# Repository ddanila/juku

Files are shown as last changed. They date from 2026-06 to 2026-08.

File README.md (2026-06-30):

# Juku models

OpenSCAD models for restoring and reproducing parts of the Juku computer.
Technical dimensions and modeling details are in [NOTES.md](NOTES.md).

> [!NOTE]
> This project is an experiment in creating medium-complexity 3D models
> with an LLM. The OpenSCAD code was written through Codex with almost no
> manual code edits.

## Models

### Keycap

The keycap has a dished top, rounded chamfered sides, a central spring rod,
contact pushers, and side latches that clip into the switch housing.

|  | Top | Bottom |
| --- | --- | --- |
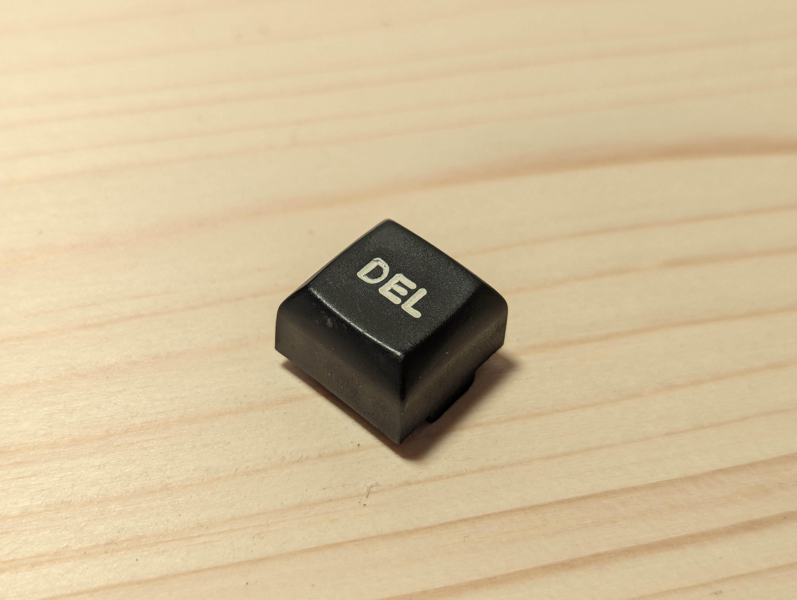
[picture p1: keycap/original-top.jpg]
Top of an original Juku keycap
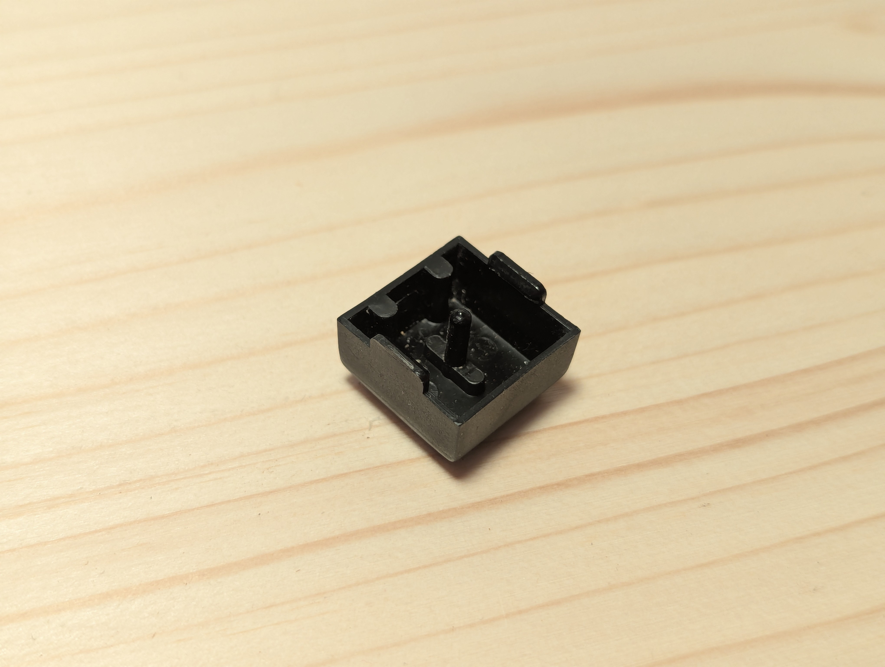
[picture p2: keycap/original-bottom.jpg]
Bottom of an original Juku keycap
| Original |  |  |
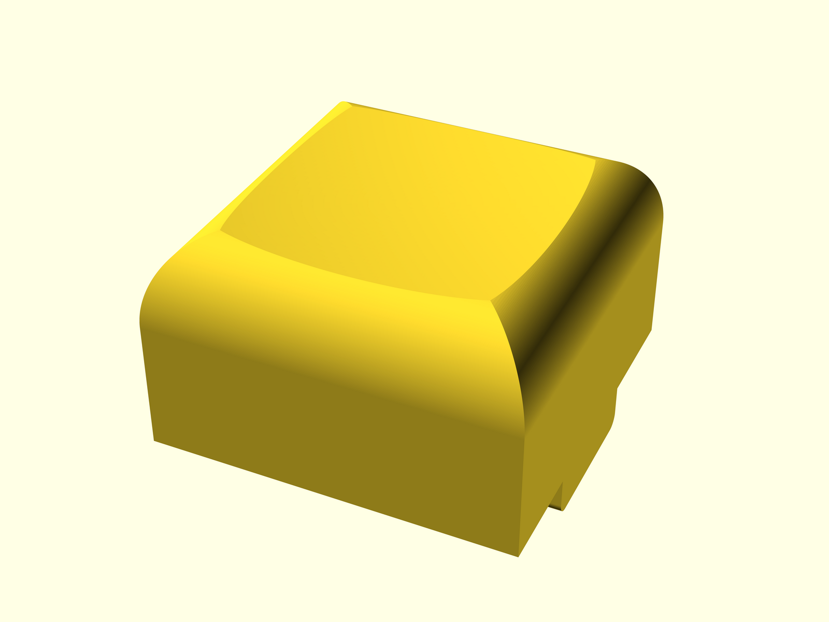
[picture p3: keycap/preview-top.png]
Top keycap render
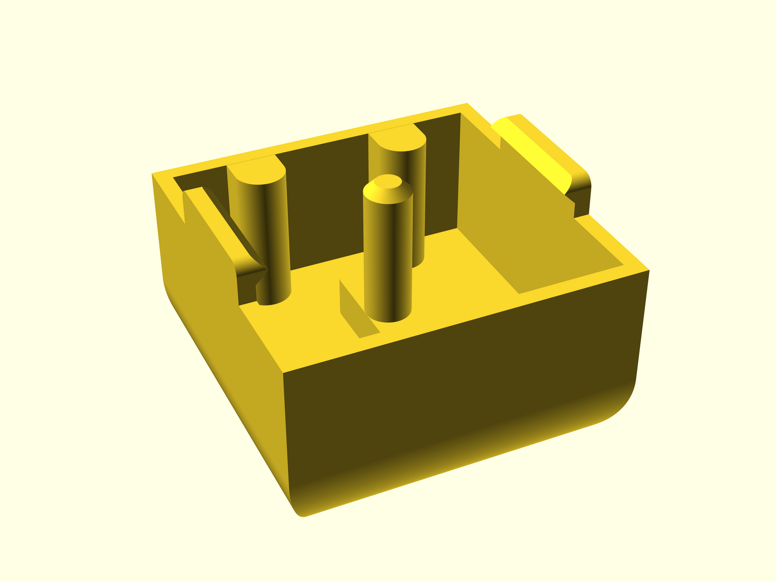
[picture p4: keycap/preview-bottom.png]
Bottom keycap render
| Render |  |  |
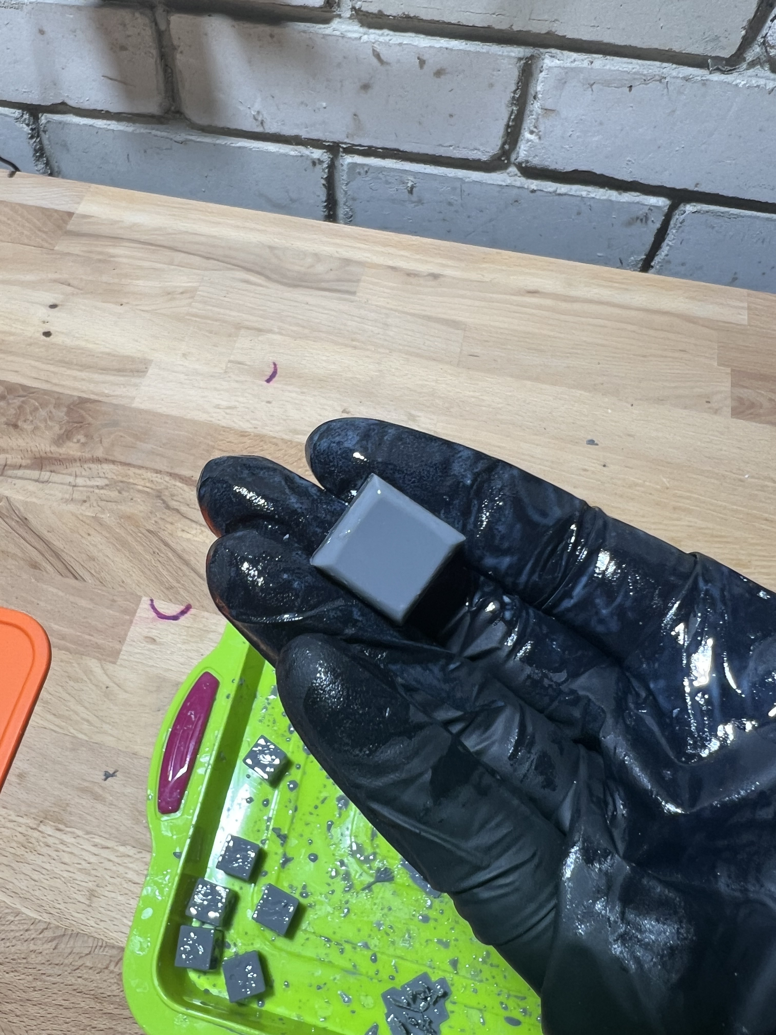
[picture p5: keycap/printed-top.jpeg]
Top of the printed keycap
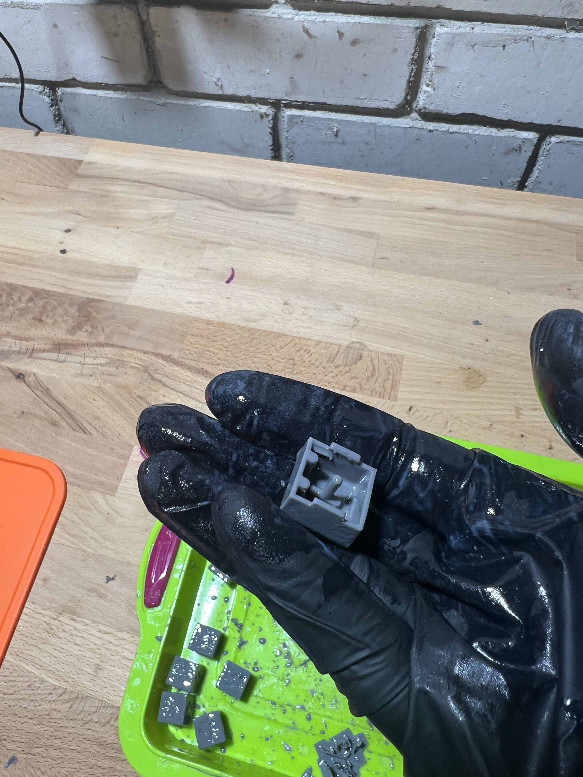
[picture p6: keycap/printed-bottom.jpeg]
Bottom of the printed keycap
| Print |  |  |

- Source: [`keycap/juku-keycap.scad`](keycap/juku-keycap.scad)
- Printable model: [`keycap/juku-keycap.stl`](keycap/juku-keycap.stl)

### Bottom Case

The bottom part of the computer case includes the PCB opening and guide,
leg mounting holes, and reinforced PCB support mounts.

| Interior | Underside (logo) | Rear edge (supports) |
| --- | --- | --- |
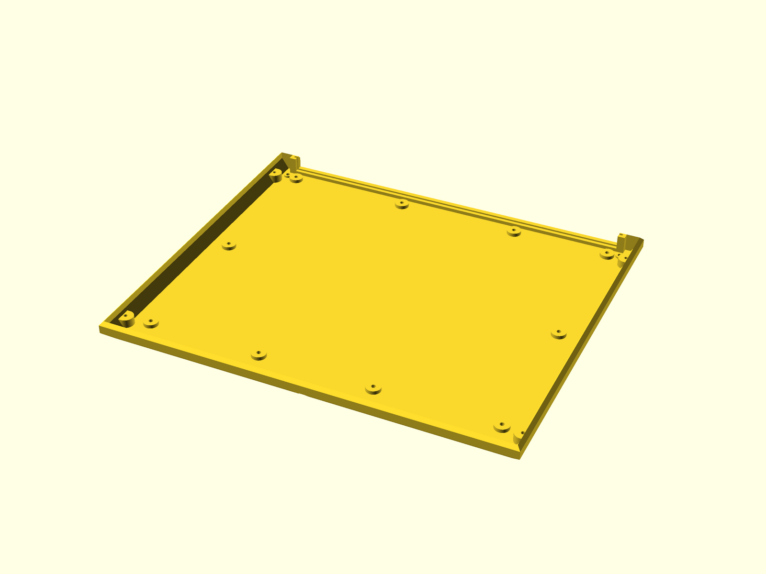
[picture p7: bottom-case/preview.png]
Bottom case interior render
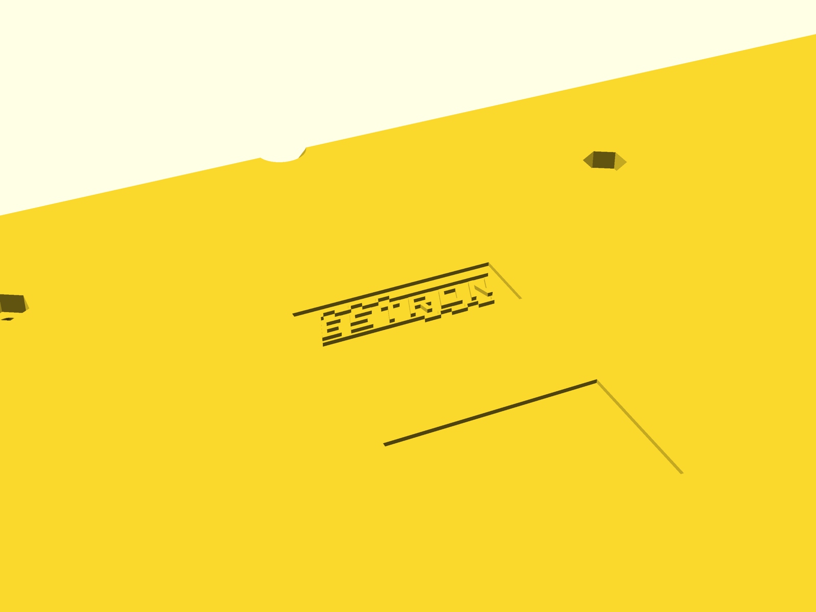
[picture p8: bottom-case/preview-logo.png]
Bottom case underside render with logo
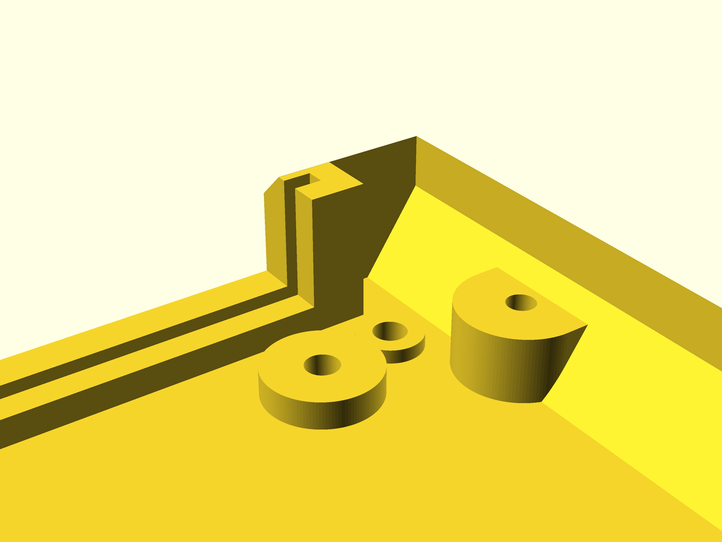
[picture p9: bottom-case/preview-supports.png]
Bottom case rear-edge render showing guide rails and support bosses
|  |  |  |

- Source: [`bottom-case/juku-bottom-case.scad`](bottom-case/juku-bottom-case.scad)
- Printable model: [`bottom-case/juku-bottom-case.stl`](bottom-case/juku-bottom-case.stl)

### Top Case

The top case is an open-bottom shell with a sloped keyboard face, keyboard
opening, side-wall chamfers, rear ventilation slots, a recessed logo area,
LED opening, and switch access opening.

| Exterior | Interior |
| --- | --- |
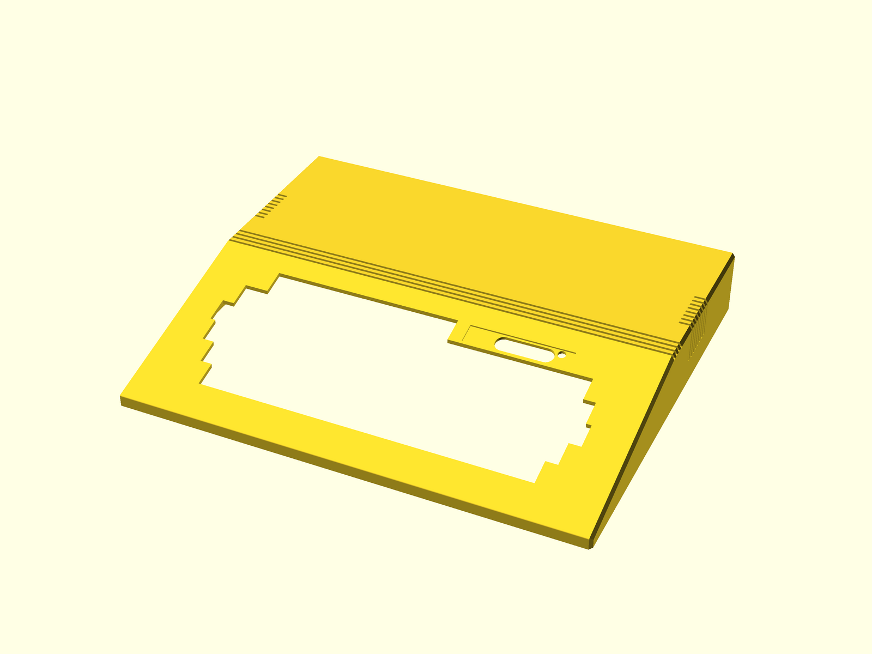
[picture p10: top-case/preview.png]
Top case exterior render
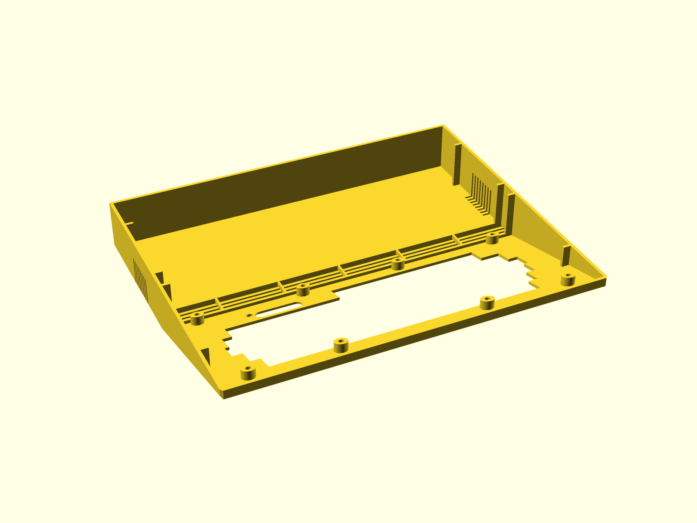
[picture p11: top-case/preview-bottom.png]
Top case interior render
|  |  |

- Source: [`top-case/juku-top-case.scad`](top-case/juku-top-case.scad)
- Printable model: [`top-case/juku-top-case.stl`](top-case/juku-top-case.stl)

### Legs

The rubber legs are simple stepped push-in feet matched to the bottom-case
mounting holes.

| Render |
| --- |
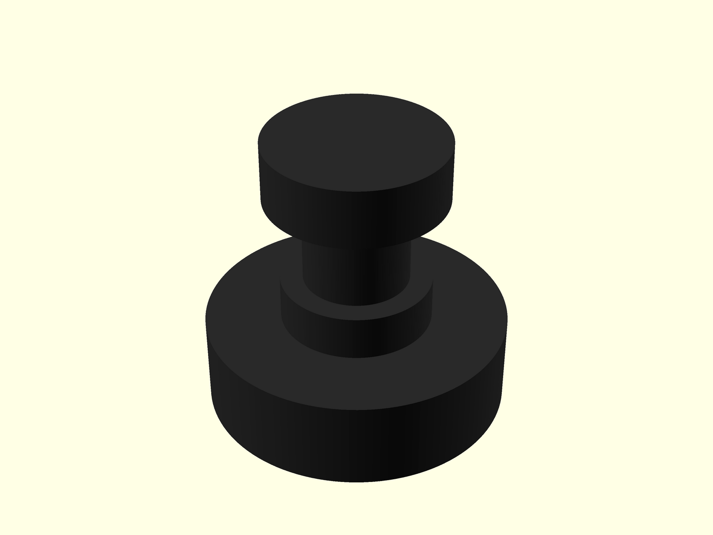
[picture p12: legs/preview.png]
Leg render
|  |

- Source: [`legs/juku-leg.scad`](legs/juku-leg.scad)
- Printable/reference model: [`legs/juku-leg.stl`](legs/juku-leg.stl)
- Assembly check: [`assembly/juku-bottom-with-legs.scad`](assembly/juku-bottom-with-legs.scad)

## Commands

```bash
# Open a model for interactive inspection.
./scripts/open-keycap.sh
./scripts/open-bottom-case.sh

# Validate both models without changing committed artifacts.
./scripts/check-render.sh

# Regenerate committed STL files and previews.
./scripts/export-stls.sh
./scripts/render-previews.sh

# Export the bottom-case XY projection for LibreCAD.
openscad-nightly \
    -o bottom-case/projection-xy.dxf \
    bottom-case/projection-xy.scad
```

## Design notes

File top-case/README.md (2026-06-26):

# Juku Top Case

OpenSCAD model for the top half of the Juku computer case.

Top case preview

## Files

- Source: [`juku-top-case.scad`](juku-top-case.scad)
- Printable/reference model: [`juku-top-case.stl`](juku-top-case.stl)
- Preview render: [`preview.png`](preview.png)

## Current Model

The top case is an open-bottom shell with a sloped keyboard face, keyboard
opening, side-wall chamfers, rear ventilation slots, a recessed logo area, LED
hole, and rounded config-switch access opening.

The main dimensions and feature offsets are named near the top of
`juku-top-case.scad`. Keep changes parameterized there where practical.

## Regeneration

From the repository root:

```bash
./scripts/export-stls.sh
./scripts/render-previews.sh
```

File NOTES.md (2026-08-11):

# Juku Modeling Notes

## OpenSCAD command

OpenSCAD is installed through Snap as `openscad-nightly`, not `openscad`.

```bash
openscad-nightly --version
```

If a plain `openscad` command is useful, add this alias to `~/.bashrc`:

```bash
alias openscad=openscad-nightly
```

On macOS the binary is inside the app bundle: `/Applications/OpenSCAD.app/Contents/MacOS/OpenSCAD`.

## Repository layout

Each modeled component keeps its source and generated artifacts together:

| Component | Source | Generated artifacts |
| --- | --- | --- |
| Keycap | `keycap/juku-keycap.scad` | `keycap/juku-keycap.stl`, `keycap/preview-*.png` |
| Bottom case | `bottom-case/juku-bottom-case.scad` | `bottom-case/juku-bottom-case.stl`, `bottom-case/preview.png` |
| Legs | `legs/juku-leg.scad` | `legs/juku-leg.stl` |

Regenerate STL files with `./scripts/export-stls.sh` and previews with
`./scripts/render-previews.sh`. Generated model artifacts should not be
edited by hand.

The preview script renders above the target resolution and downscales to
1600x1200 because OpenSCAD's CLI renders without antialiasing. It uses
OpenSCAD's built-in `Monotone` color scheme so subtraction-cut surfaces do
not get a distinct back-face color.

`keycap/original-*.jpg` are reference photos of an original keycap.
`keycap/printed-*.jpeg` are photos of a real resin print, with metadata
stripped.

## Iteration workflow

After each modeling change:

1. Render the SCAD file to an STL to catch syntax and geometry errors.

   ```bash
   ./scripts/check-render.sh
   ```

2. Confirm OpenSCAD reports a manifold 3D object with `Status: NoError`.

3. Open the SCAD file in OpenSCAD for manual review from a normal desktop terminal or the application launcher.

   ```bash
   ./scripts/open-keycap.sh
   ./scripts/open-bottom-case.sh
   ```

Codex can run the automated render check reliably. It can also attempt to launch the OpenSCAD UI, but Snap/desktop session handling may make that window flash briefly or disappear, so manual review is best started from the user's desktop session.

## Modeling notes

Large spheres used for shallow cuts need a high local segment count. A large-radius sphere with the global `$fn = 48` can technically intersect the model but look flat in OpenSCAD because the visible patch is a low-resolution facet. Use a local `$fn`, for example:

```scad
sphere(r = top_dish_radius, $fn = top_dish_segments);
```

## Bottom case dimensions

All dimensions are in millimeters.

| Dimension | Value |
| --- | ---: |
| Outer width (X) | 340 |
| Outer depth (Y) | 290 |
| Outer height (Z) | 18 |
| Case thickness | 3 |
| Front and side bottom chamfer | 8 at 45 degrees |
| Top rim chamfer | 3 at 45 degrees, downward toward outside |
| Rear PCB opening | 300 wide x 12 high, centered horizontally and open at top |
| Rear outer guide rail | 312 long x 4 deep x 15 high |
| Rear guide channel | 2 deep, with the case floor at its bottom |
| Rear inner guide rail | 306 long x 3 deep x 15 high |
| Leg hole centers | 15 from each adjacent outer edge |
| Leg through-hole | 3.5 diameter |
| Leg exterior counterbore | 5 diameter x 1.5 deep |
| Leg interior reinforcement | 7 diameter x 1.5 high |
| Leg through-hole depth | 4.5 including floor and reinforcement boss |
| Leg hole cylinder segments | 128 |
| PCB support through-hole | 3.5 diameter |
| PCB support exterior nut pocket | Hexagonal, 6 across flats x 3 deep |
| PCB support interior reinforcement | 12 diameter x 3 high |
| PCB support rear row centers | X: 25, 129, 233, 315; Y: 272 |
| PCB support side centers | X: 25, 315; Y: 152 |
| PCB support front row centers | X: 25, 120, 215, 315; Y: 32 |
| Lid mount side centers | X: 7, 333; Y: 25, 265 |
| Lid mount front center | X: 170; Y: 7 |
| Lid mount through-hole | 3 diameter |
| Lid mount exterior recess | 8 wide x 6.5 deep, round-ended and projected to outer edge |
| Lid mount interior reinforcement | 13 diameter x 7 high, clipped to D shape |
| Logo plaque | 30 wide x 10 deep x 0.6 recessed into underside |
| Logo plaque front offset | 50 to front edge |
| Logo relief | 0.6 above recessed plaque floor, flush with underside |
| Serial plate recess | 30 wide x 20 deep x 0.6 recessed into underside |
| Serial plate recess gap | 20 behind Estron plaque |

The case is an open-top shell with 3 mm walls and floor. The front and both
sides have an 8 mm external bottom chamfer; the rear remains square. The
inner chamfer is offset to keep the sloped material 3 mm thick. The top rim
slopes from the inside lip downward and outward across the full wall
thickness. A rectangular PCB opening is centered horizontally in the rear
wall and extends downward from the top edge. The maximum outer envelope
starts at the origin.

The experimental PCB guide aligns vertically with the rear opening. Its
outer face aligns with the exterior rear face. Moving inward, the
arrangement is a 4 mm rail, a 2 mm channel, and a 3 mm rail. Both rails are
centered; the outer rail extends 3 mm farther at each end, where square
mirrored bridges close the channel. The 300 mm opening is cut through the
rear wall and the complete guide depth from Z=6 to Z=18. The guide extends
down to the inner floor at Z=3, leaving a continuous 3 mm-high base beneath
the opening. Its exterior top edge has the same 3 mm, 45-degree chamfer as
the case rim.

Four leg mounting holes are positioned symmetrically near the corners. Each
has a through-hole, a concentric counterbore entering from the exterior
underside, and a concentric reinforcement boss rising from the inner floor.
The mounting interface dimensions are shared from
`bottom-case/leg-interface.scad` so the leg model and assembly check fail at
render time if the mating diameters or heights drift apart.

The rubber/latex/silicone leg is a stepped push-in part. From exterior to
interior it has a 10 diameter x 3 high foot, a 5 diameter x 1.5 high
counterbore plug, a 3.5 diameter x 3 high stem through the case floor, and a
6 diameter x 2 high inner retaining head.

Ten PCB supports form three centered rows. The rear and front rows have four
supports each, while the middle row has one support at each shared outer X
coordinate. Each support has a through-hole, a 3 mm-deep hexagonal nut
pocket entering from the exterior underside, and a 12 mm-diameter
reinforcement boss rising 3 mm from the inner floor.

Five top-lid mounts sit in the front and side bottom-chamfer bands. Four are
paired near the front and rear ends of the side walls, and one is centered
on the front wall. Their inner bosses and exterior recesses have round inner
ends with straight projections toward the adjacent wall, forming D-shaped
profiles.

The exterior underside has a centered 30 x 10 mm logo plaque whose front
edge is 50 mm from the front of the case. Its background is recessed 0.6 mm
into the case, leaving the imported Estron letters and decorative lines
standing 0.6 mm above the plaque floor, flush with the original underside.
The vector source is `bottom-case/estron-logo.dxf`.

A second plain rectangular recess for the model and serial-number plate is
centered on the underside. It measures 30 x 20 mm, has the same 0.6 mm
depth, and starts 20 mm behind the rear edge of the Estron plaque.

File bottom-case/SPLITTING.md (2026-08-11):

# Bottom case — staggered 4-part split for small print beds

The assembled bottom case is **340 × 290 mm**. That does not fit a common
**256 × 256 mm** bed, so `juku-bottom-case-split.scad` cuts it into four panels
joined by half-lap seams and glued back together. The front and rear vertical
seams are offset, producing two T-junctions rather than one four-way crossing.

> **You only need this if your bed is too small.** The one-piece
> `juku-bottom-case.scad` is the canonical model and is left completely
> untouched. With a printer of ~300 mm or wider, print that file and ignore the
> split entirely.

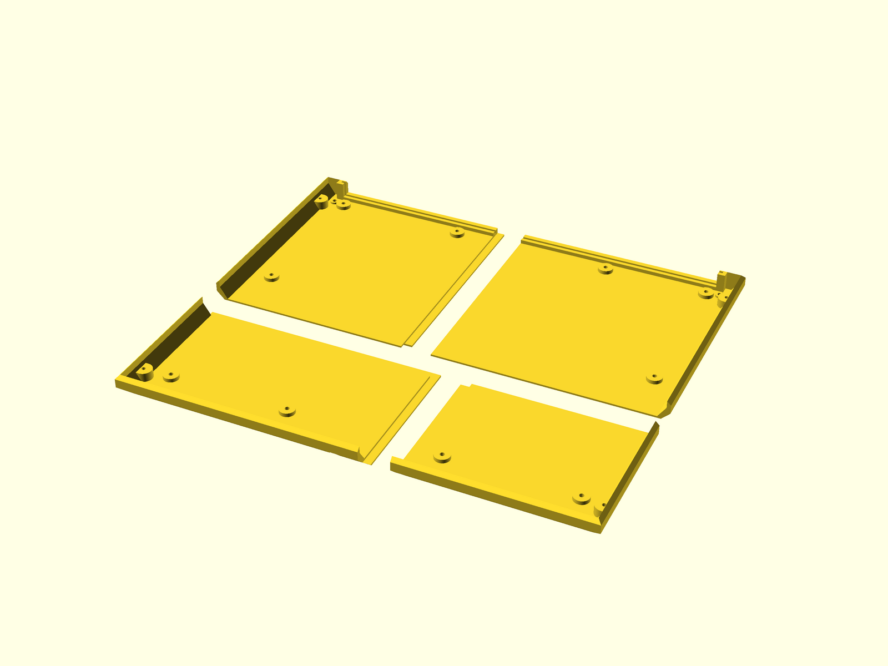
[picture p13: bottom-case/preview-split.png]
Exploded preview of the four panels


## Why four pieces

A piece fits the bed if its long side ≤ 256, or — laid diagonally — if
`long + short ≲ 256·√2 ≈ 362`.

For axis-aligned rectangular partitions, two or three pieces leave at least one
part too large for a 256 mm bed. Four pieces fit flat with comfortable margin,
without diagonal placement or unusual slicer setup. More elaborate irregular
partitions may exist, but saving one print is not worth their harder seam
routing and assembly.

The obvious four-piece layout is a 2×2 grid. This model instead staggers the X
seam by 35 mm between the front and rear regions. Removing the four-way crossing
has three practical benefits:

- front and rear pairs can be glued and clamped independently;
- their completed halves are then joined across the Y seam;
- no continuous X seam runs through the full depth of the case.

## How the model is built

`juku-bottom-case-split.scad` does **not** redefine the case. It pulls in the
original with `use <juku-bottom-case.scad>`, then intersects it with two
half-lap selectors (one per seam) to carve out each panel.

### Cut planes

| Plane | Value | Clears |
|---|---|---|
| `split_x_front` | **195** | centred logo/serial recesses (155–185), front-centre lid boss (170), front PCB-support bosses |
| `split_x_rear` | **160** | rear PCB-support bosses; staggers the X seam by 35 mm |
| `split_y` | **115** | PCB-support rows (32 / 152 / 272), lid-mount bosses (25 / 265) |

Resulting panels — nominal size plus the half-lap shelf each laps past the
seam (`+ lap_width/2`), all ≤ 256:

| Panel | Width × Depth (incl. lap) | STL | Preview |
|---|---|-----|---|
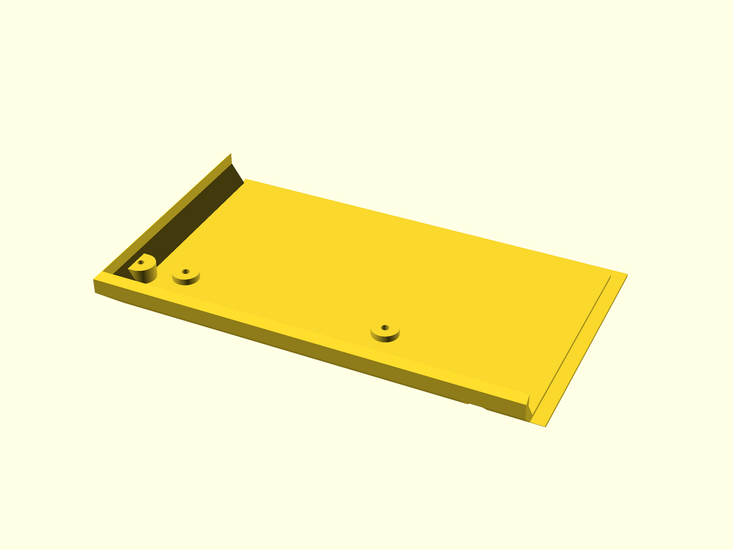
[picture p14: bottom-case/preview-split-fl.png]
fl
| `fl` front-left  | 198 × 118 | [`juku-bottom-case-fl.stl`](juku-bottom-case-fl.stl) |  |
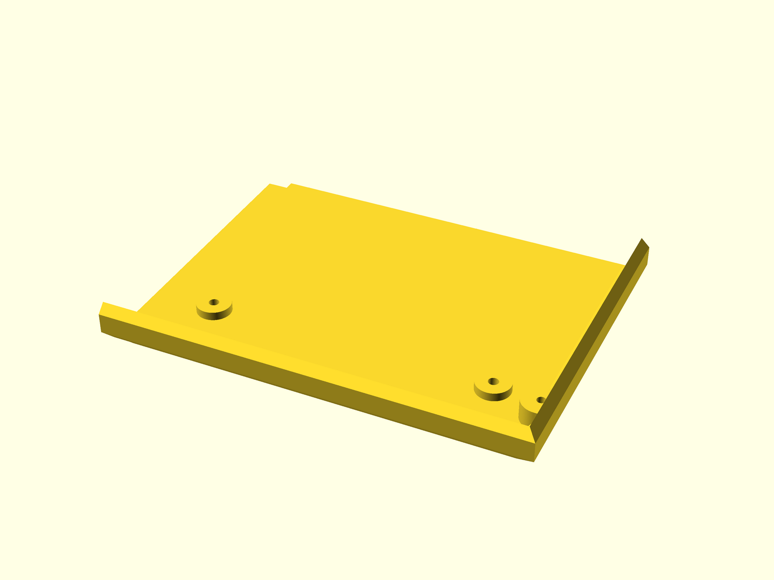
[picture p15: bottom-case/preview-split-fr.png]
fr
| `fr` front-right | 148 × 118 | [`juku-bottom-case-fr.stl`](juku-bottom-case-fr.stl) |  |
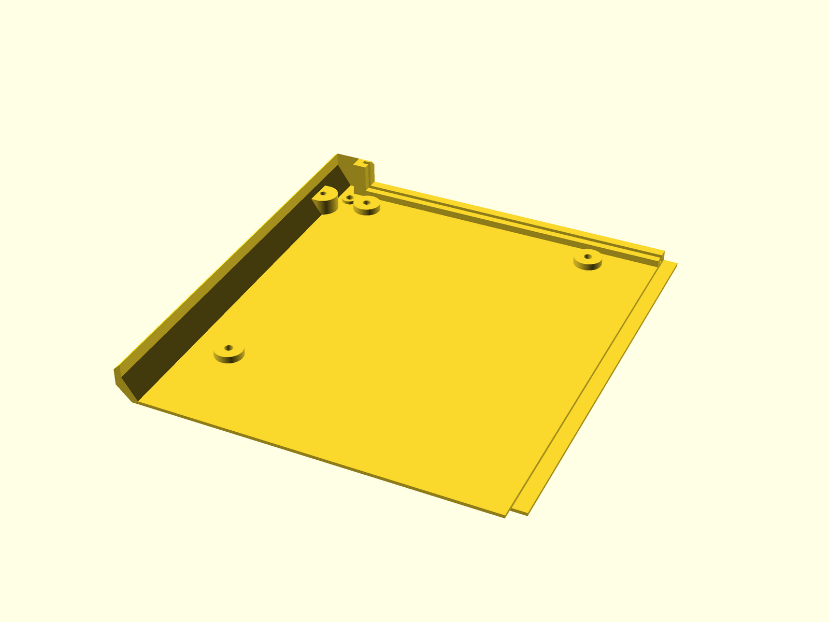
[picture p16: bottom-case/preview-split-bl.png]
bl
| `bl` back-left | 163 × 178 | [`juku-bottom-case-bl.stl`](juku-bottom-case-bl.stl) |  |
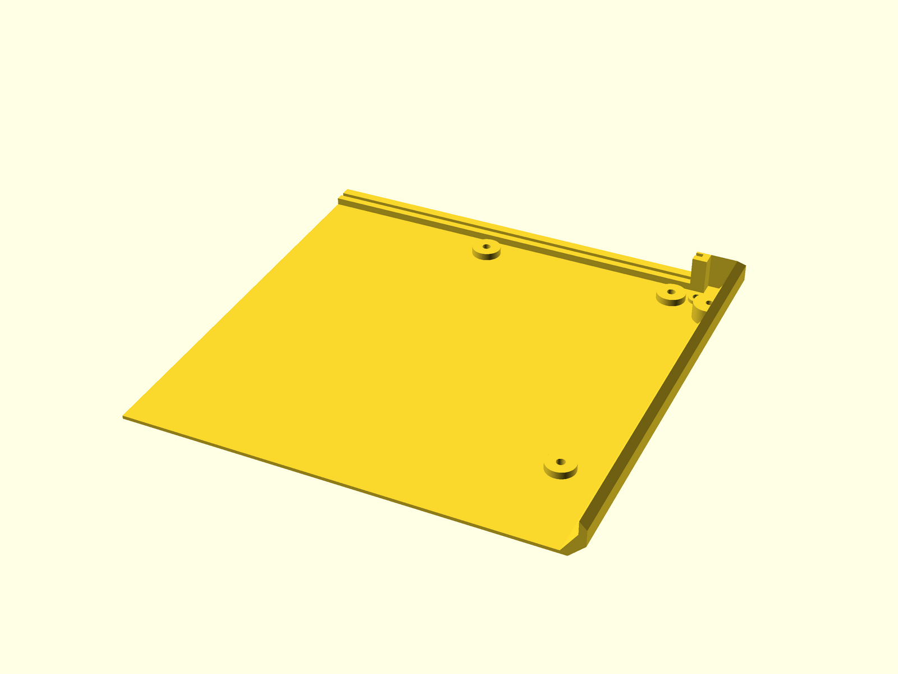
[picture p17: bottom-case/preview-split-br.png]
br
| `br` back-right  | 183 × 178 | [`juku-bottom-case-br.stl`](juku-bottom-case-br.stl) |  |

### Half-lap seams

Each seam is a **half-lap worked into the 3 mm floor thickness** rather than a
flat butt joint. The cut steps in Z partway through the floor and offsets
sideways, so one piece carries the top shelf past the seam and the other the
bottom shelf; the shelves overlap, locate each other in Z, and are glued.

```
cross-section across a seam (3 mm thick):
    LEFT  ###########
          ###########            <- top shelf (left)
          ------=========        <- step at lap_step
                =========        <- bottom shelf (right)  RIGHT
          |<- lap_width ->|
```

- Because the step lives **inside the floor**, the taller perimeter walls are
  simply cut straight (a butt joint) — no thin features weakening them.
- Defaults: `lap_width = 6 mm` (shelf overlap), `lap_step = 1.5 mm` (even
  halves; set `1.0` for a thinner bottom shelf).
- `split_kerf = 0.2 mm` is removed from every mating face as a slip-fit / glue
  gap.

The lapped shelves handle Z-alignment; glue across the overlap carries the load.

## Rendering & exporting

The four panel STLs and previews are committed alongside this file and are
regenerated by the repo scripts:

```bash
scripts/export-stls.sh       # writes juku-bottom-case-{fl,fr,bl,br}.stl
scripts/render-previews.sh   # writes preview-split.png + preview-split-*.png
```

To work with a single panel by hand — preview all four exploded apart
(default), or export one (`fl` / `fr` / `bl` / `br`):

```bash
osc=/Applications/OpenSCAD.app/Contents/MacOS/OpenSCAD   # or: openscad-nightly
"$osc" juku-bottom-case-split.scad                       # exploded preview
"$osc" -o fl.stl --export-format binstl --backend Manifold \
    -D 'split_part="fl"' juku-bottom-case-split.scad
```

The console echoes each panel footprint and the build asserts every piece
fits `bed_size` (default 256) — bump `bed_size` if your printer is larger and
you still want a (coarser) split.

## Assembly

1. Print all four panels flat (floor down).
2. Dry-fit: slide the lapped shelves together and confirm they close flush and
   the floor sits coplanar. Adjust `split_kerf` if the fit is too tight/loose.
3. Glue the front pair (`fl` + `fr`) and rear pair (`bl` + `br`) separately,
   clamping each pair until set.
4. Glue the two completed halves across the Y seam and clamp until set.
5. The lap handles Z alignment; the glued overlap carries the load.

## Tuning

All knobs live at the top of `juku-bottom-case-split.scad`: `split_x_front`,
`split_x_rear`, `split_y`, `split_kerf`, `bed_size`, `lap_width` and
`lap_step`. If you change a case dimension in `juku-bottom-case.scad`, update
the mirrored constants near the top of the split file (they are flagged with a
comment).

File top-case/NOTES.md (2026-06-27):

# Top Case Notes

All dimensions are in millimeters.

The top case is an open-bottom shell. The main front/back/top body is built
from a single extruded side profile so OpenSCAD preview does not show stray
internal vectors from overlapping wall and top pieces. The left and right
side walls are separate 3 mm profiles added to close the sides while keeping
the underside open for the computer internals.

The keyboard opening is modeled as six row cutouts. Row parameters are kept
near the top of `juku-top-case.scad` so the measured offsets and row widths
can be adjusted without changing the construction modules.

The front top edge roundover is a subtractive cutter applied after the shell
and side walls are unioned. Keeping it out of the base profiles preserves the
separate side-wall chamfers while letting the roundover continue across the
full front edge.

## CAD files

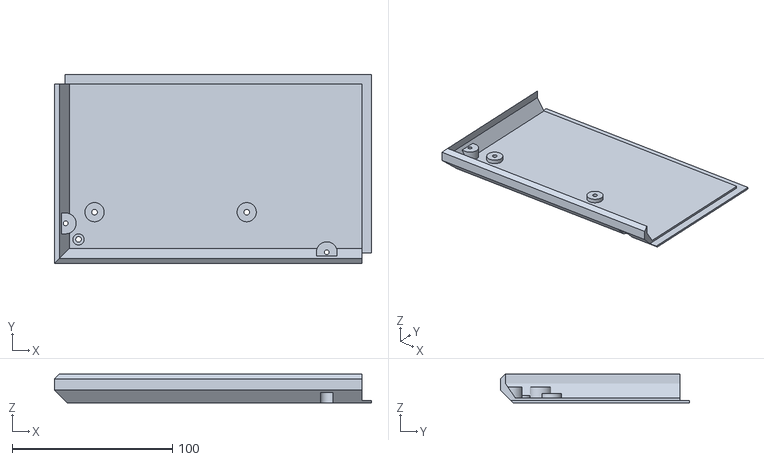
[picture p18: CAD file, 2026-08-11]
bottom-case/juku-bottom-case-fl.stl
197.9 x 117.9 x 18.0

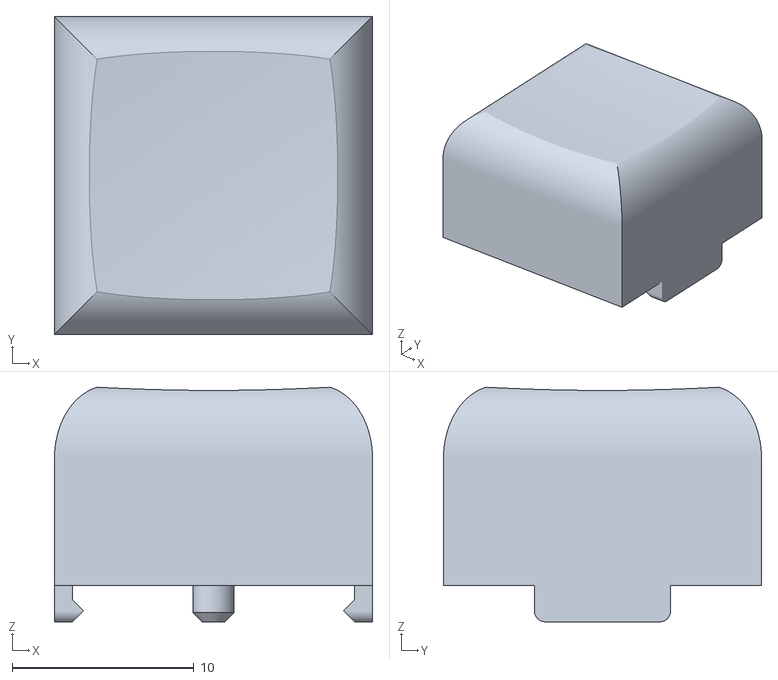
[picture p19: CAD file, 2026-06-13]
keycap/juku-keycap.stl
17.5 x 17.5 x 12.9

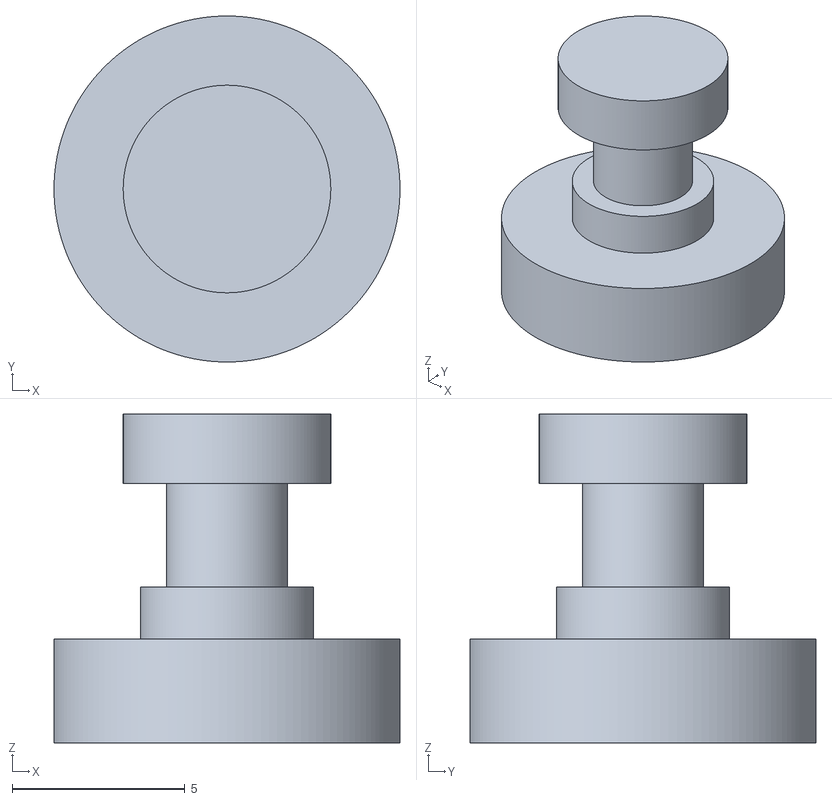
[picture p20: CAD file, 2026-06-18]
legs/juku-leg.stl
10.0 x 10.0 x 9.50

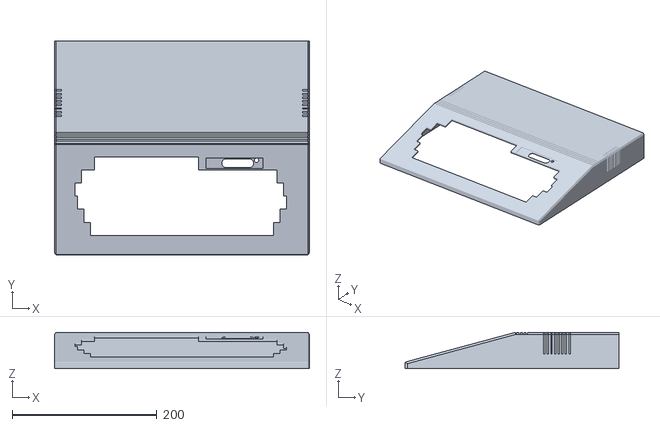
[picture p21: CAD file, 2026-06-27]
top-case/juku-top-case.stl
352.0 x 295.0 x 50.0

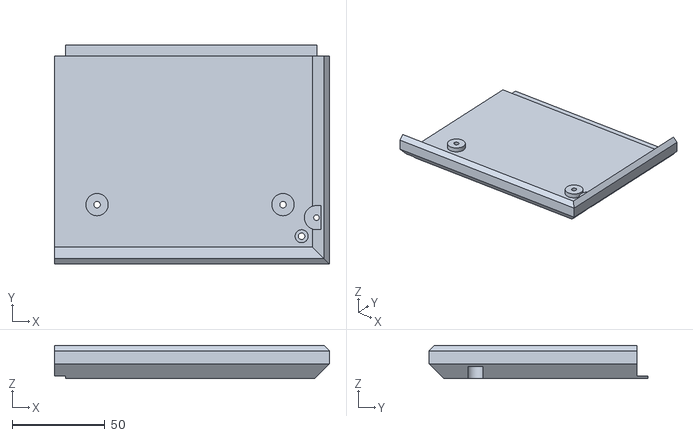
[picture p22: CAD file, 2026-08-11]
bottom-case/juku-bottom-case-fr.stl
147.9 x 117.9 x 18.0

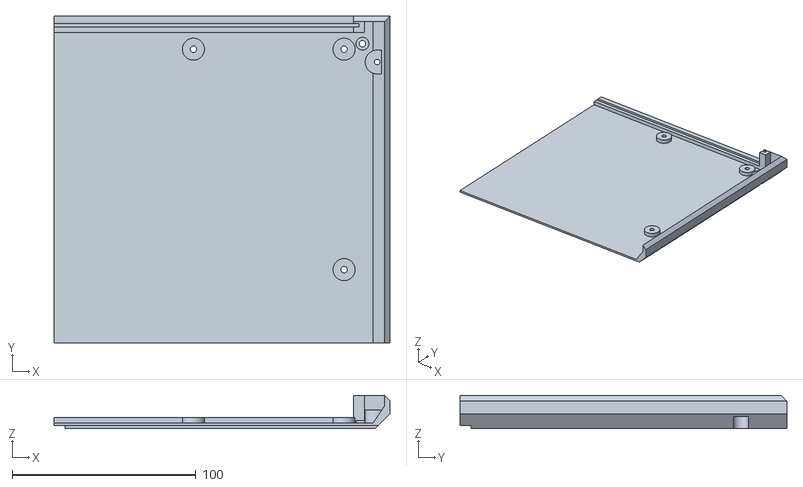
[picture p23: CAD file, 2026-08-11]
bottom-case/juku-bottom-case-br.stl
182.9 x 177.9 x 18.0

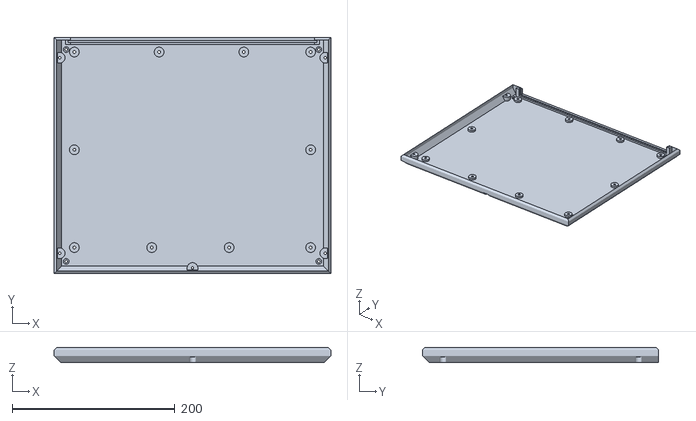
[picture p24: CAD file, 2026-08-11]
bottom-case/juku-bottom-case.stl
340.0 x 290.0 x 18.0

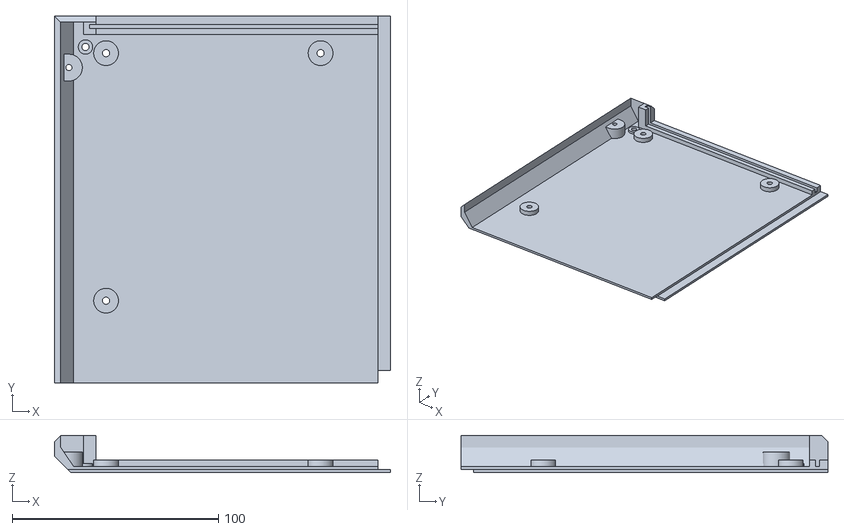
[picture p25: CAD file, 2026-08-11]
bottom-case/juku-bottom-case-bl.stl
162.9 x 177.9 x 18.0

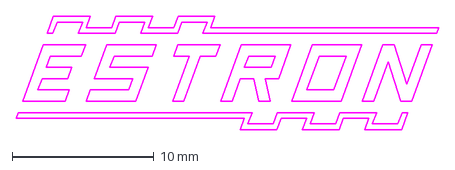
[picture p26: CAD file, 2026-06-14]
bottom-case/estron-logo.dxf
29.8 x 8.00 mm

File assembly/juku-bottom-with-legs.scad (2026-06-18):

// Juku bottom case with rubber legs installed
// Units: millimeters

include <../bottom-case/leg-interface.scad>

use <../bottom-case/juku-bottom-case.scad>
use <../legs/juku-leg.scad>

outside_width = 340;
outside_depth = 290;

bottom_case();

leg_mount_positions(outside_width, outside_depth)
    juku_leg();

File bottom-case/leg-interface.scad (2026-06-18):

// Shared bottom-case leg mounting interface
// Units: millimeters

leg_hole_edge_offset = 15;
leg_hole_diameter = 3.5;
leg_counterbore_diameter = 5;
leg_counterbore_depth = 1.5;
leg_boss_diameter = 7;
leg_boss_height = 1.5;
leg_through_hole_depth = 4.5;
leg_hole_segments = 128;

module leg_mount_positions(
    outside_width,
    outside_depth
) {
    for (
        x = [
            leg_hole_edge_offset,
            outside_width - leg_hole_edge_offset
        ],
        y = [
            leg_hole_edge_offset,
            outside_depth - leg_hole_edge_offset
        ]
    ) {
        translate([x, y, 0])
            children();
    }
}

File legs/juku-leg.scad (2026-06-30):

// Juku bottom-case rubber leg
// Units: millimeters

include <../bottom-case/leg-interface.scad>

leg_outer_diameter = 10;
leg_outer_height = 3;
leg_counterbore_plug_diameter = 5;
leg_counterbore_plug_height = 1.5;
leg_stem_diameter = 3.5;
leg_stem_height = 3;
leg_inner_retainer_diameter = 6;
leg_inner_retainer_height = 2;
leg_segments = 128;

module juku_leg_fit_check() {
    assert(leg_outer_diameter > leg_counterbore_plug_diameter);
    assert(leg_outer_height > 0);
    assert(leg_counterbore_plug_diameter <= leg_counterbore_diameter);
    assert(leg_counterbore_plug_height <= leg_counterbore_depth);
    assert(leg_stem_diameter <= leg_hole_diameter);
    assert(leg_stem_height > 0);
    assert(
        leg_counterbore_plug_height + leg_stem_height
        == leg_through_hole_depth
    );
    assert(leg_inner_retainer_diameter > leg_stem_diameter);
    assert(leg_inner_retainer_diameter <= leg_boss_diameter);
    assert(leg_inner_retainer_height > 0);
    assert(leg_segments >= 3);
}

module juku_leg() {
    juku_leg_fit_check();

    color([0.16, 0.16, 0.16])
        union() {
            translate([0, 0, -leg_outer_height])
                cylinder(
                    h = leg_outer_height,
                    d = leg_outer_diameter,
                    $fn = leg_segments
                );

            cylinder(
                h = leg_counterbore_plug_height,
                d = leg_counterbore_plug_diameter,
                $fn = leg_segments
            );

            translate([0, 0, leg_counterbore_plug_height])
                cylinder(
                    h = leg_stem_height,
                    d = leg_stem_diameter,
                    $fn = leg_segments
                );

            translate([
                0,
                0,
                leg_counterbore_plug_height + leg_stem_height
            ])
                cylinder(
                    h = leg_inner_retainer_height,
                    d = leg_inner_retainer_diameter,
                    $fn = leg_segments
                );
        }
}

juku_leg();

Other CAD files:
bottom-case/juku-bottom-case-split.scad
bottom-case/juku-bottom-case.scad
bottom-case/projection-xy.scad
keycap/juku-keycap.scad
top-case/juku-top-case.scad

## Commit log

2026-06-02 Initial keycap model
    [juku_keycap.scad]
2026-06-02 Add spring rod
    [juku_keycap.scad]
2026-06-02 Add rounded spring rod base
    [juku_keycap.scad]
2026-06-02 Add shallow spherical top dish
    [juku_keycap.scad]
2026-06-02 Tune top chamfer and dish
    [juku_keycap.scad]
2026-06-02 Tune top dish radius
    [juku_keycap.scad]
2026-06-02 Add contact pushers
    [juku_keycap.scad]
2026-06-02 Shape contact pushers into side projections
    [juku_keycap.scad]
2026-06-02 Add latch prototype
    [juku_keycap.scad]
2026-06-02 Tune latch teeth
    [juku_keycap.scad]
2026-06-02 Round latch side edges
    [juku_keycap.scad]
2026-06-03 Increase render resolution and parametrize latch rounding
    - Bump chamfer_steps 18->128 and top_dish_segments 256->1024
    - Raise global $fn 48->128
    - Add latch_round_segments param (32), replacing hardcoded arc steps
    [juku_keycap.scad]
2026-06-11 Add README, STL export and rendered previews
    The SCAD file stays the single source; the STL and PNGs are generated
    artifacts, regenerated via openscad export and scripts/render-previews.sh.
2026-06-11 Add photos of the resin-printed keycap
    Metadata (EXIF/XMP) stripped; only the color profile is kept.
2026-06-11 Switch STL export to binary and mark STL as binary in git
2026-06-11 Add print photos to README next to renders
2026-06-12 Add initial Juku bottom case model
    [juku_bottom_case.scad]
2026-06-12 Add bottom edge chamfers to case
    [juku_bottom_case.scad]
2026-06-12 Chamfer the top rim of bottom case
    [juku_bottom_case.scad]
2026-06-12 Add rear PCB opening to bottom case
    [juku_bottom_case.scad]
2026-06-12 Add rear PCB guide to bottom case
    [juku_bottom_case.scad]
2026-06-13 Add reinforced leg mounting holes
    [juku_bottom_case.scad]
2026-06-13 Add reinforced PCB support mounts
    [juku_bottom_case.scad]
2026-06-13 Organize models and generated assets
    [juku-bottom-case.scad, juku-bottom-case.stl, juku-keycap.scad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]
2026-06-13 Add bottom case XY projection helper
    [projection-xy.scad]
2026-06-13 Add reinforced top lid mounting holes
    [juku-bottom-case.scad, juku-bottom-case.stl]
2026-06-13 Extend lid mount bosses to case walls
    [juku-bottom-case.scad, juku-bottom-case.stl]
2026-06-14 Add recessed Estron logo to bottom case
    [estron-logo.dxf, juku-bottom-case.scad, juku-bottom-case.stl]
2026-06-14 Add serial plate recess to bottom case
    [juku-bottom-case.scad, juku-bottom-case.stl]
2026-06-15 Add underside and rear-edge bottom-case previews
    - Add zoomed underside (logo) and rear-edge (supports) renders, shown
    alongside the interior render in the README.
    - Over-cut the rear PCB opening past the top rim so it clears the
    top-edge chamfer remnant (removed a hairline in the renders; the
    printed solid is unchanged).
    - Render previews with the Manifold backend.
    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
    [juku-bottom-case.scad]
2026-06-15 Add 4-part split of bottom case for small print beds
    The 340x290 bottom case does not fit a 256x256 bed, so add a separate
    juku-bottom-case-split.scad that reuses the one-piece model unchanged
    (via `use`) and cuts it into a 2x2 grid of quadrants joined by half-lap
    seams worked into the 3mm floor thickness. Includes the four quadrant
    STLs, previews, and SPLITTING.md. Build scripts export/render/check the
    split alongside the canonical one-piece model.
    [juku-bottom-case-bl.stl, juku-bottom-case-br.stl, juku-bottom-case-fl.stl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]
2026-06-18 Adjust bottom case leg bosses
    [juku-bottom-case.scad]
2026-06-18 Add bottom case leg model
    [juku-bottom-case.scad, juku-bottom-with-legs.scad, juku-leg.scad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]
2026-06-26 Add initial top case model
    [juku-top-case.scad]
2026-06-26 Add top case keyboard opening
    [juku-top-case.scad]
2026-06-26 Add top case side chamfers
    [juku-top-case.scad]
2026-06-26 Add top case ventilation slots
    [juku-top-case.scad]
2026-06-26 Add top case logo recess
    [juku-top-case.scad]
2026-06-26 Add top case LED hole
    [juku-top-case.scad]
2026-06-26 Add top case switch access hole
    [juku-top-case.scad]
2026-06-26 Add top case generated artifacts
    [juku-top-case.stl]
2026-06-27 Add top case side vents
    [juku-top-case.scad]
2026-06-27 Add top case front roundover
    [juku-top-case.scad, juku-top-case.stl]
2026-06-27 Add top case vent reinforcements
    [juku-top-case.scad]
2026-06-27 Add top case vent cross reinforcements
    [juku-top-case.scad]
2026-06-27 Add rear side wall reinforcements
    [juku-top-case.scad]
2026-06-27 Add front side wall reinforcements
    [juku-top-case.scad]
2026-06-27 Add top case keyboard supports
    [juku-top-case.scad]
2026-06-28 Shift top case keyboard supports
    [juku-top-case.scad]
2026-06-30 Update keycap dimensions
    [juku-keycap.scad]
2026-06-30 Add top case to README
2026-06-30 Add missing model previews
    [juku-leg.scad]
2026-07-01 Restore keycap dish radius
    [juku-keycap.scad]
2026-08-05 Regenerate keycap STL
2026-08-07 Regenerate split bottom-case STLs
    [juku-bottom-case-bl.stl, juku-bottom-case-br.stl, juku-bottom-case-fl.stl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]
2026-08-11 Stagger bottom case split and adjust PCB mounts
    [juku-bottom-case-bl.stl, juku-bottom-case-br.stl, juku-bottom-case-split.scad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]
2026-08-11 Deepen bottom case lid mount recesses
    [juku-bottom-case-bl.stl, juku-bottom-case-br.stl, juku-bottom-case-fl.stl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]
